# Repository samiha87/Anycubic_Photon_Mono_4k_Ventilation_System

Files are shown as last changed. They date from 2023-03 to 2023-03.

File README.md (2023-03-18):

CAD Design: FreeCAD
Slicer: Cura

CAD printer and material:
  Printer: Anycubic Vyper
  Print Material: PLA, 0.1 Layer height
  
Hardware:
 Fan: Noctua NF-A4X10-FLX 5V https://www.amazon.de/-/en/dp/B00NEMGCIA
 USB-C PCB https://www.aliexpress.com/item/1005004829778290.html
 Solder fan red wire to VBUS
 Solder fan black wire to GND

Scaling for printed screw
  - Screw size for the attachment used M33, scale 0.990
  - Screw cut for the fastener used M33, Scale 1.050

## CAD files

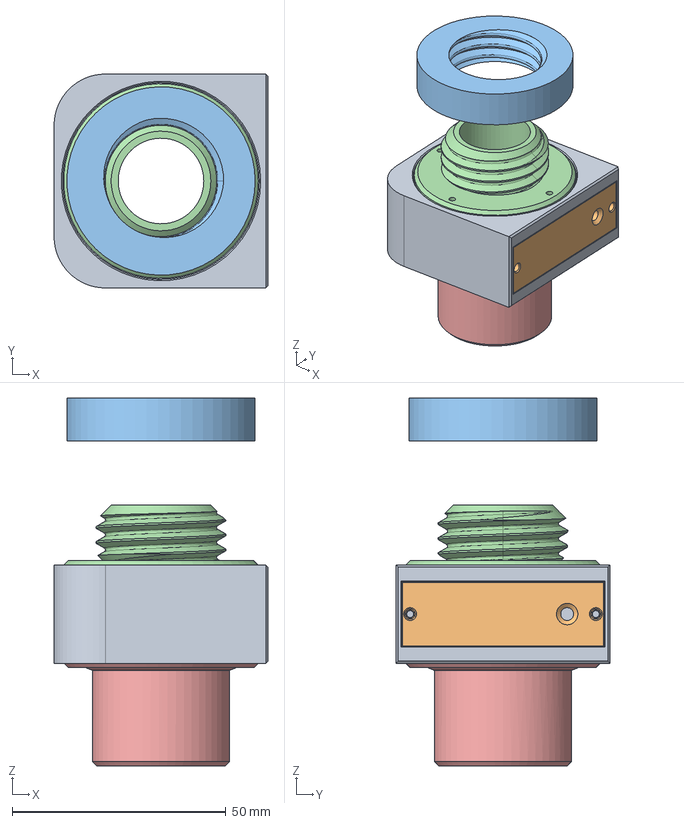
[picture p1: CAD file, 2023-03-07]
Air_Ventilation_System.FCStd
50.0 x 50.0 x 86.0 mm
Fan_Box
Fan_Box_Hatch
Fan_Fastener_Fusion
Fan_Attachment_Screw
Fan_Attachment_Inner_Tube

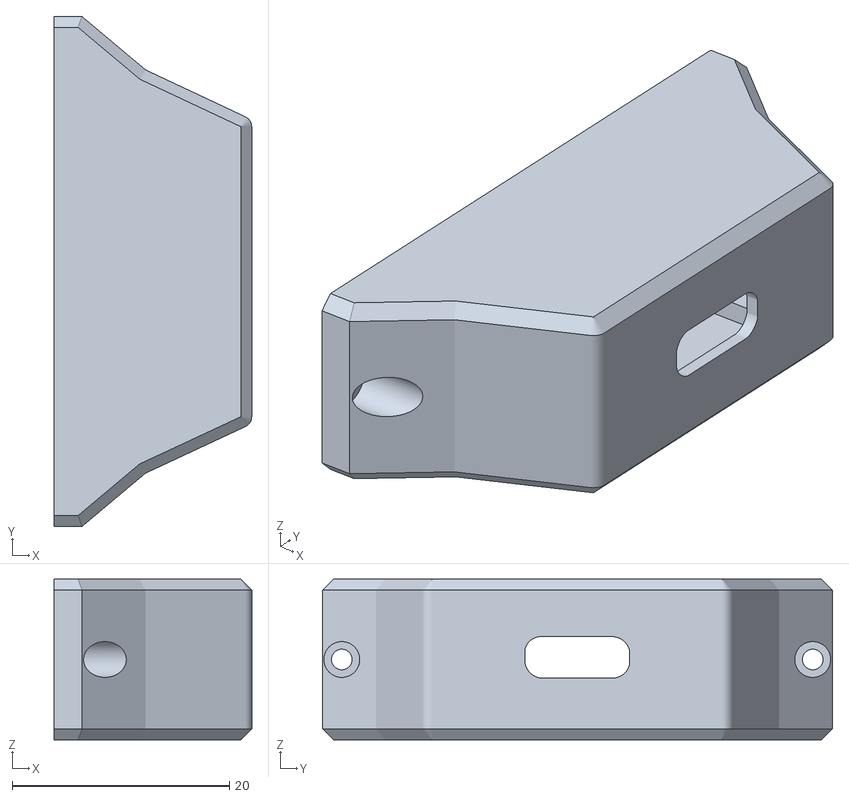
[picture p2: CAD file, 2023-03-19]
Exported_STL/Power_Supply_Case.stl
18.2 x 47.0 x 14.8

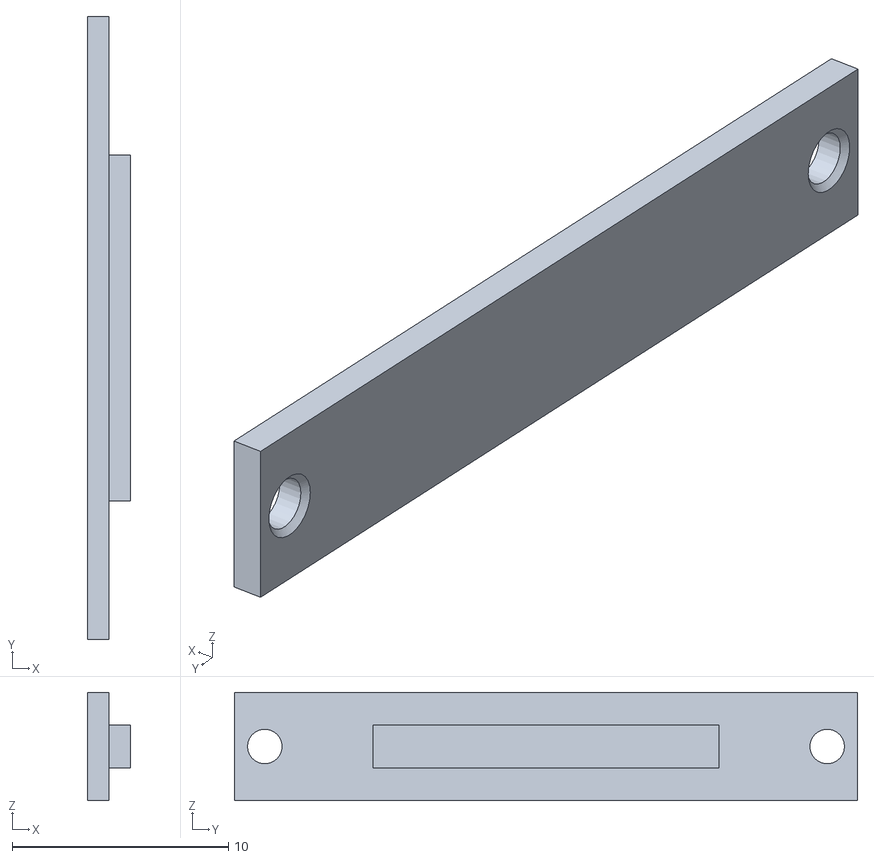
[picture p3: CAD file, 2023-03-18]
Exported_STL/Power_Supply_Case_PCB_Support.stl
2.00 x 28.8 x 5.00

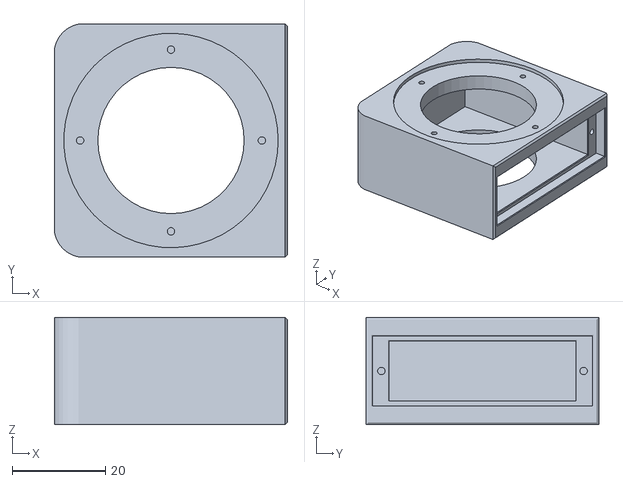
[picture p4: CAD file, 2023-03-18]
Exported_STL/Fan_Enclosure.stl
50.0 x 50.0 x 23.0

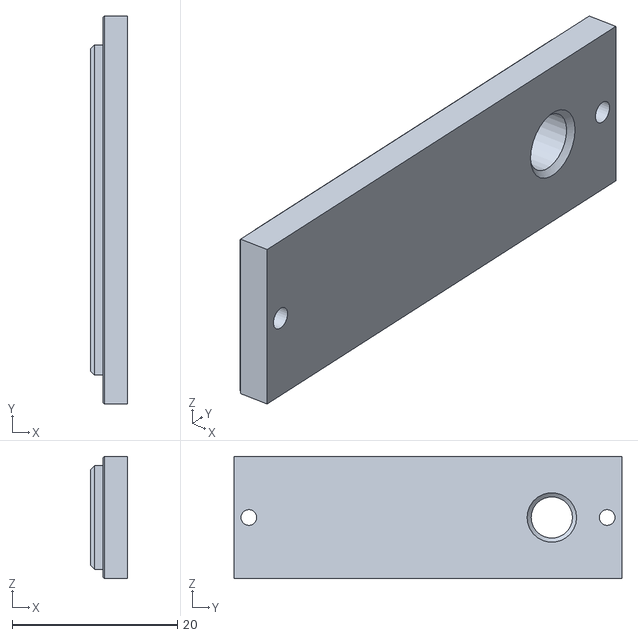
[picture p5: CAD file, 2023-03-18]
Exported_STL/Fan_Hatch.stl
4.50 x 47.0 x 14.8

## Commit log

2023-03-07 Seperated tube and screw attachment from main body
    [Air_Ventilation_System.FCStd, Cura_Vent_Fan_enclosure.3mf]
2023-03-08 Added spacers for WhamBam
2023-03-08 Added chamfer for fan hatch cable hole
2023-03-08 Added chamfer for fan hatch
2023-03-08 Added KiCAD schematic
    [Fan_Control.kicad_pcb, Fan_Control.kicad_sch]
2023-03-09 re-adjusted fan hatch size
2023-03-10 Added more tolerance to fan, modified tolerances of screw attachment and fastener, due not previously fitting after printing
2023-03-12 Added parts to the schematic and started with circuit design
    [Fan_Control.kicad_sch]
2023-03-12 Added more tolerance and chamfer for screw fastener
2023-03-12 Made whambam spacers slightly smaller
2023-03-14 Added part to hold the power supply
    [Fan_Control.kicad_sch]
2023-03-14 Added pcb support and hardware details to readme
2023-03-14 Cleaned folder
    [Fan_Control.kicad_sch]
2023-03-14 Documented correct scale for attachmen screw and fastener
2023-03-18 Added stl files, with higher resolution and increased power supply case usb pocket size
    [Cura_Vent_Fan_enclosure.3mf, Fan_Attachment_Inner_Tube.stl, Fan_Enclosure.stl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]
2023-03-19 Increased USB pocket size
    [Fan_Attachment_Inner_Tube.stl, Power_Supply_Case.stl, WhamBam_Spacer.stl]
